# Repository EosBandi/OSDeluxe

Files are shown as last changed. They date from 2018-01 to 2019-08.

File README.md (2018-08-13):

# OSDeluxe

OSDeluxe is a color OSD with four video input, Picture in Picture function for Mavlink flight controllers. It using a Renesas TW2837 Video Mux ASIC
and a Teensy 3.2.

# History

This project, just like many others has a long history. It started as “blue screen” eliminator, for FPV flights. Before custom made FPV monitors, it was a constant problem that normal monitors went dark or blue when video signal become noisy. A cheap video quad switch based on a TW2823 (earlier version of the chip currently used) was reprogrammed to digitize incoming video in a free running mode, and since it already had four inputs and PIP capabilities it was also added to the mix. (The idea come from a Russian webpage http://we.easyelectronics.ru/howwork/kvadrator-izobrazheniya-dlya-sistem-videonablyudeniya.html and “confidential” datasheet of TW2823 was found on Chinese page.) 
The TW2823 chip has color OSD capabilities and it seemed a good idea to make a PIP OSD for FPV use with it. After experimenting for a while it turned out that the speed of OSD functions are too slow to use  for FPV, so the project was stalled. Then a new version of the chip come out, the TW2837 with accelerated OSD functions. Using these functions with some tuned code, now it is possible to have a decent color OSD with around 10Hz refresh rate.

# TW2837
The TW2837 is a four channel video and audio controller designed for security applications by Renesas (Originally TechWell, then Intersil…). It has four PAL/NTSC video decoders (digitizers) and dual video encoders. Video encoders has scalers and video enhancer built in. Decoders and encoders are connected to a MUX engine which provides two display paths and an accelerated graphic overlay (OSD) for each paths. Unlike older TW28xx chips, datasheet for TW2837 is freely available.  (unfortunately OSD sections of the datasheet are quite rudimentary, so it needed a lot’s of experimenting to make it work.)
Communication with the chip can be done via I2C interface (up to 10Mhz!! clock speed) or via a parallel interface.

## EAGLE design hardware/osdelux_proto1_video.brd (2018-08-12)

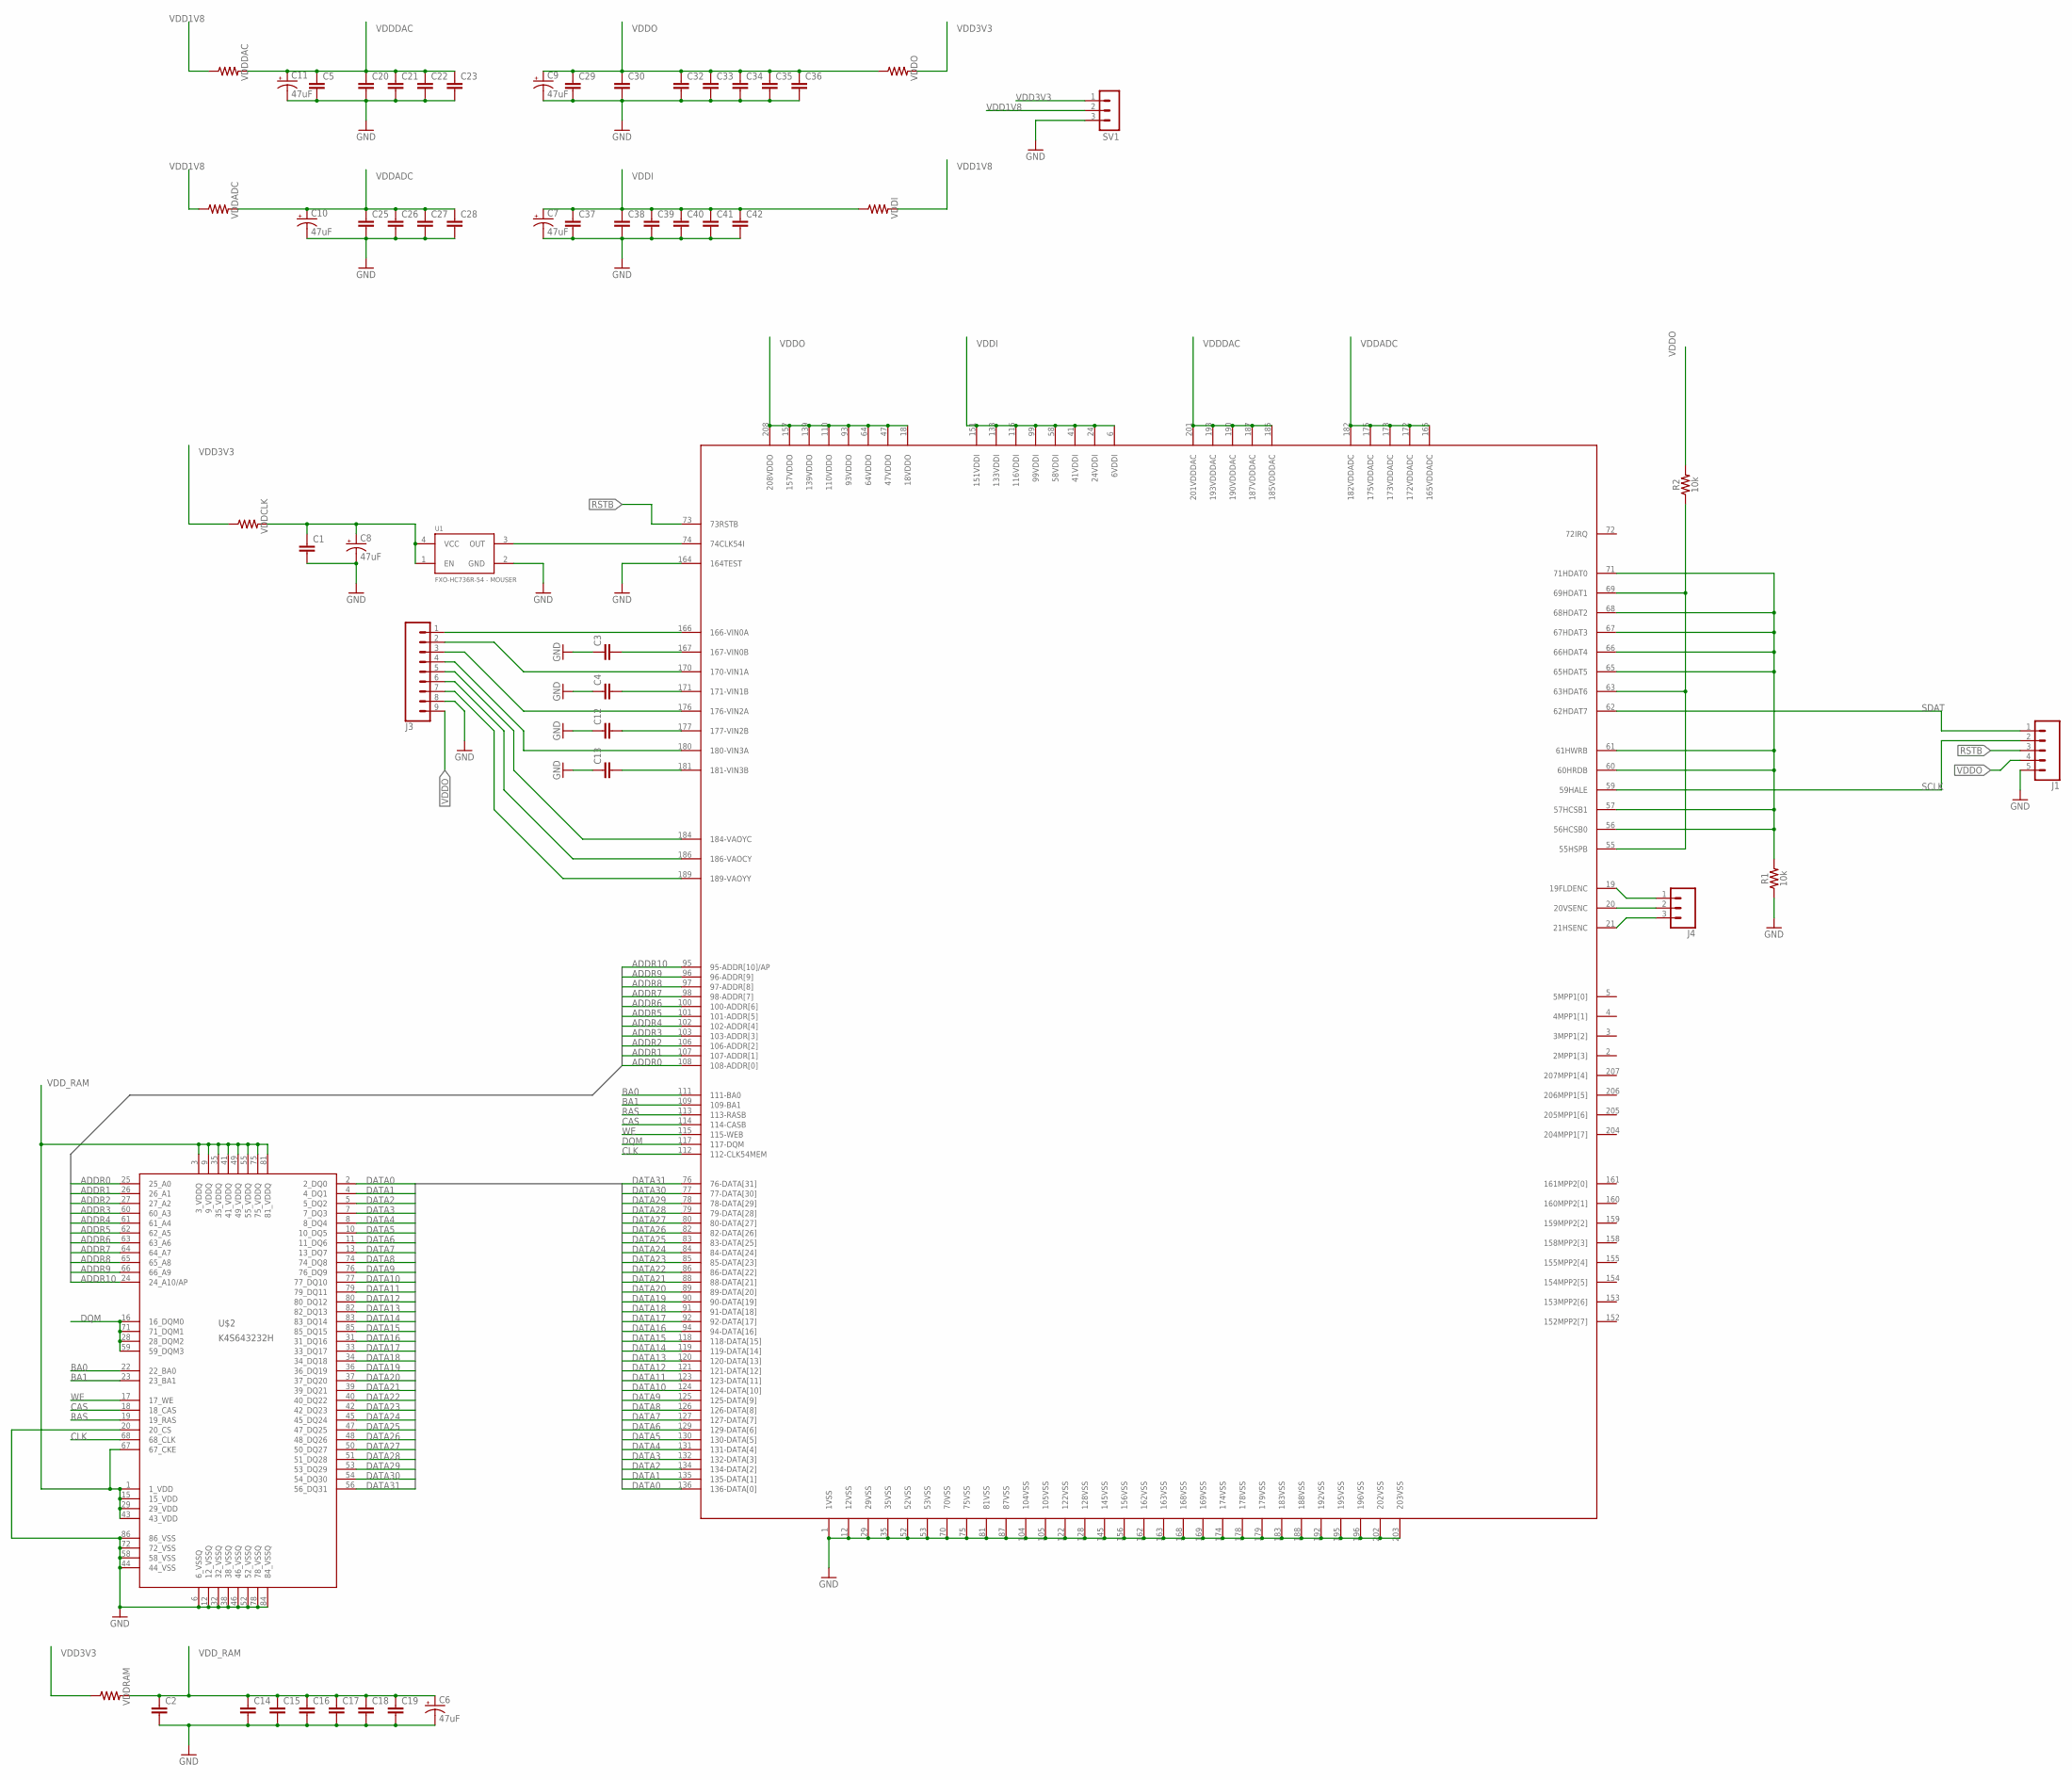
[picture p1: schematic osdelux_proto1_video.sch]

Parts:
C1, C2, C3, C4, C5, C12, C13, C14, C15, C16, C17, C18, C19, C20, C21, C22, C23, C25, C26, C27, C28, C29, C30, C32, C33, C34, C35, C36, C37, C38, C39, C40, C41, C42: CAP0805; 0805
C6, C7, C8, C9, C10, C11: 47uF; EIA3528
J1: CONN_05LOCK_LONGPADS; 1X05_LOCK_LONGPADS
J3: CONN_09LOCK-LONGPADS; 1X09_LOCK_LONGPADS
J4: CONN_03LOCK_LONGPADS; 1X03_LOCK_LONGPADS
R1, R2: 10k; 0805
SV1: MA03-1
U1: FXO-HC736R-54 - MOUSER; CRYSTAL-SMD-7.5X5.2-6PIN
U$1: TW2823; LQFP208
U$2: K4S643232H; TSOP86
VDDADC: 1206
VDDCLK: 1206
VDDDAC: 1206
VDDI: 1206
VDDO: 1206
VDDRAM: 1206

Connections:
72IRQ: U$1.72 (72IRQ)
ADDR0: U$1.108 (108-ADDR[0]), U$2.25 (25_A0)
ADDR1: U$1.107 (107-ADDR[1]), U$2.26 (26_A1)
ADDR2: U$1.106 (106-ADDR[2]), U$2.27 (27_A2)
ADDR3: U$1.103 (103-ADDR[3]), U$2.60 (60_A3)
ADDR4: U$1.102 (102-ADDR[4]), U$2.61 (61_A4)
ADDR5: U$1.101 (101-ADDR[5]), U$2.62 (62_A5)
ADDR6: U$1.100 (100-ADDR[6]), U$2.63 (63_A6)
ADDR7: U$1.98 (98-ADDR[7]), U$2.64 (64_A7)
ADDR8: U$1.97 (97-ADDR[8]), U$2.65 (65_A8)
ADDR9: U$1.96 (96-ADDR[9]), U$2.66 (66_A9)
ADDR10: U$1.95 (95-ADDR[10]/AP), U$2.24 (24_A10/AP)
BA0: U$1.111 (111-BA0), U$2.22 (22_BA0)
BA1: U$1.109 (109-BA1), U$2.23 (23_BA1)
CAS: U$1.114 (114-CASB), U$2.18 (18_CAS)
CLK: U$1.112 (112-CLK54MEM), U$2.68 (68_CLK)
DATA0: U$1.136 (136-DATA[0]), U$2.2 (2_DQ0)
DATA1: U$1.135 (135-DATA[1]), U$2.4 (4_DQ1)
DATA2: U$1.134 (134-DATA[2]), U$2.5 (5_DQ2)
DATA3: U$1.132 (132-DATA[3]), U$2.7 (7_DQ3)
DATA4: U$1.131 (131-DATA[4]), U$2.8 (8_DQ4)
DATA5: U$1.130 (130-DATA[5]), U$2.10 (10_DQ5)
DATA6: U$1.129 (129-DATA[6]), U$2.11 (11_DQ6)
DATA7: U$1.127 (127-DATA[7]), U$2.13 (13_DQ7)
DATA8: U$1.126 (126-DATA[8]), U$2.74 (74_DQ8)
DATA9: U$1.125 (125-DATA[9]), U$2.76 (76_DQ9)
DATA10: U$1.124 (124-DATA[10]), U$2.77 (77_DQ10)
DATA11: U$1.123 (123-DATA[11]), U$2.79 (79_DQ11)
DATA12: U$1.121 (121-DATA[12]), U$2.80 (80_DQ12)
DATA13: U$1.120 (120-DATA[13]), U$2.82 (82_DQ13)
DATA14: U$1.119 (119-DATA[14]), U$2.83 (83_DQ14)
DATA15: U$1.118 (118-DATA[15]), U$2.85 (85_DQ15)
DATA16: U$1.94 (94-DATA[16]), U$2.31 (31_DQ16)
DATA17: U$1.92 (92-DATA[17]), U$2.33 (33_DQ17)
DATA18: U$1.91 (91-DATA[18]), U$2.34 (34_DQ18)
DATA19: U$1.90 (90-DATA[19]), U$2.36 (36_DQ19)
DATA20: U$1.89 (89-DATA[20]), U$2.37 (37_DQ20)
DATA21: U$1.88 (88-DATA[21]), U$2.39 (39_DQ21)
DATA22: U$1.86 (86-DATA[22]), U$2.40 (40_DQ22)
DATA23: U$1.85 (85-DATA[23]), U$2.42 (42_DQ23)
DATA24: U$1.84 (84-DATA[24]), U$2.45 (45_DQ24)
DATA25: U$1.83 (83-DATA[25]), U$2.47 (47_DQ25)
DATA26: U$1.82 (82-DATA[26]), U$2.48 (48_DQ26)
DATA27: U$1.80 (80-DATA[27]), U$2.50 (50_DQ27)
DATA28: U$1.79 (79-DATA[28]), U$2.51 (51_DQ28)
DATA29: U$1.78 (78-DATA[29]), U$2.53 (53_DQ29)
DATA30: U$1.77 (77-DATA[30]), U$2.54 (54_DQ30)
DATA31: U$1.76 (76-DATA[31]), U$2.56 (56_DQ31)
DQM: U$1.117 (117-DQM), U$2.16 (16_DQM0), U$2.28 (28_DQM2), U$2.59 (59_DQM3), U$2.71 (71_DQM1)
FLD: J4.1, U$1.19 (19FLDENC)
GND: C1.2, C2.2, C3.1, C4.1, C5.2, C6.C (-), C7.C (-), C8.C (-), C9.C (-), C10.C (-), C11.C (-), C12.1, C13.1, C14.2, C15.2, C16.2, C17.2, C18.2, C19.2, C20.2, C21.2, C22.2, C23.2, C25.2, C26.2, C27.2, C28.2, C29.2, C30.2, C32.2, C33.2, C34.2, C35.2, C36.2, C37.2, C38.2, C39.2, C40.2, C41.2, C42.2, J1.5, J3.8, R1.1, SV1.3, U1.2 (GND), U$1.1 (1VSS), U$1.12 (12VSS), U$1.29 (29VSS), U$1.35 (35VSS), U$1.52 (52VSS), U$1.53 (53VSS), U$1.70 (70VSS), U$1.75 (75VSS), U$1.81 (81VSS), U$1.87 (87VSS), U$1.104 (104VSS), U$1.105 (105VSS), U$1.122 (122VSS), U$1.128 (128VSS), U$1.145 (145VSS), U$1.156 (156VSS), U$1.162 (162VSS), U$1.163 (163VSS), U$1.164 (164TEST), U$1.168 (168VSS), U$1.169 (169VSS), U$1.174 (174VSS), U$1.178 (178VSS), U$1.179 (179VSS), U$1.183 (183VSS), U$1.188 (188VSS), U$1.192 (192VSS), U$1.195 (195VSS), U$1.196 (196VSS), U$1.202 (202VSS), U$1.203 (203VSS), U$2.6 (6_VSSQ), U$2.12 (12_VSSQ), U$2.20 (20_CS), U$2.32 (32_VSSQ), U$2.38 (38_VSSQ), U$2.44 (44_VSS), U$2.46 (46_VSSQ), U$2.52 (52_VSSQ), U$2.58 (58_VSS), U$2.72 (72_VSS), U$2.78 (78_VSSQ), U$2.84 (84_VSSQ), U$2.86 (86_VSS)
HSYNC: J4.3, U$1.21 (21HSENC)
unnamed: C1.1, C8.A (+), U1.1 (EN), U1.4 (VCC), VDDCLK.2
unnamed: U1.3 (OUT), U$1.74 (74CLK54I)
unnamed: C3.2, U$1.167 (167-VIN0B)
unnamed: C4.2, U$1.171 (171-VIN1B)
unnamed: C12.2, U$1.177 (177-VIN2B)
unnamed: C13.2, U$1.181 (181-VIN3B)
unnamed: R1.2, U$1.56 (56HCSB0), U$1.57 (57HCSB1), U$1.60 (60HRDB), U$1.61 (61HWRB), U$1.65 (65HDAT5), U$1.66 (66HDAT4), U$1.67 (67HDAT3), U$1.68 (68HDAT2), U$1.71 (71HDAT0)
unnamed: R2.1, U$1.55 (55HSPB), U$1.63 (63HDAT6), U$1.69 (69HDAT1)
RAS: U$1.113 (113-RASB), U$2.19 (19_RAS)
RSTB: J1.3, U$1.73 (73RSTB)
SCLK: J1.2, U$1.59 (59HALE)
SDAT: J1.1, U$1.62 (62HDAT7)
VAOCY: J3.6, U$1.186 (186-VAOCY)
VAOYC: J3.5, U$1.184 (184-VAOYC)
VAOYY: J3.7, U$1.189 (189-VAOYY)
VDD1V8: SV1.2, VDDADC.1, VDDDAC.1, VDDI.2
VDD3V3: SV1.1, VDDCLK.1, VDDO.2, VDDRAM.1
VDDADC: C10.A (+), C25.1, C26.1, C27.1, C28.1, U$1.165 (165VDDADC), U$1.172 (172VDDADC), U$1.173 (173VDDADC), U$1.175 (175VDDADC), U$1.182 (182VDDADC), VDDADC.2
VDDDAC: C5.1, C11.A (+), C20.1, C21.1, C22.1, C23.1, U$1.185 (185VDDDAC), U$1.187 (187VDDDAC), U$1.190 (190VDDDAC), U$1.193 (193VDDDAC), U$1.201 (201VDDDAC), VDDDAC.2
VDDI: C7.A (+), C37.1, C38.1, C39.1, C40.1, C41.1, C42.1, U$1.6 (6VDDI), U$1.24 (24VDDI), U$1.41 (41VDDI), U$1.58 (58VDDI), U$1.99 (99VDDI), U$1.116 (116VDDI), U$1.133 (133VDDI), U$1.151 (151VDDI), VDDI.1
VDDO: C9.A (+), C29.1, C30.1, C32.1, C33.1, C34.1, C35.1, C36.1, J1.4, J3.9, R2.2, U$1.18 (18VDDO), U$1.47 (47VDDO), U$1.64 (64VDDO), U$1.93 (93VDDO), U$1.110 (110VDDO), U$1.139 (139VDDO), U$1.157 (157VDDO), U$1.208 (208VDDO), VDDO.1
VDD_RAM: C2.1, C6.A (+), C14.1, C15.1, C16.1, C17.1, C18.1, C19.1, U$2.1 (1_VDD), U$2.3 (3_VDDQ), U$2.9 (9_VDDQ), U$2.15 (15_VDD), U$2.29 (29_VDD), U$2.35 (35_VDDQ), U$2.41 (41_VDDQ), U$2.43 (43_VDD), U$2.49 (49_VDDQ), U$2.55 (55_VDDQ), U$2.67 (67_CKE), U$2.75 (75_VDDQ), U$2.81 (81_VDDQ), VDDRAM.2
VIN0: J3.1, U$1.166 (166-VIN0A)
VIN1: J3.2, U$1.170 (170-VIN1A)
VIN2: J3.3, U$1.176 (176-VIN2A)
VIN3: J3.4, U$1.180 (180-VIN3A)
VSYNC: J4.2, U$1.20 (20VSENC)
WE: U$1.115 (115-WEB), U$2.17 (17_WE)

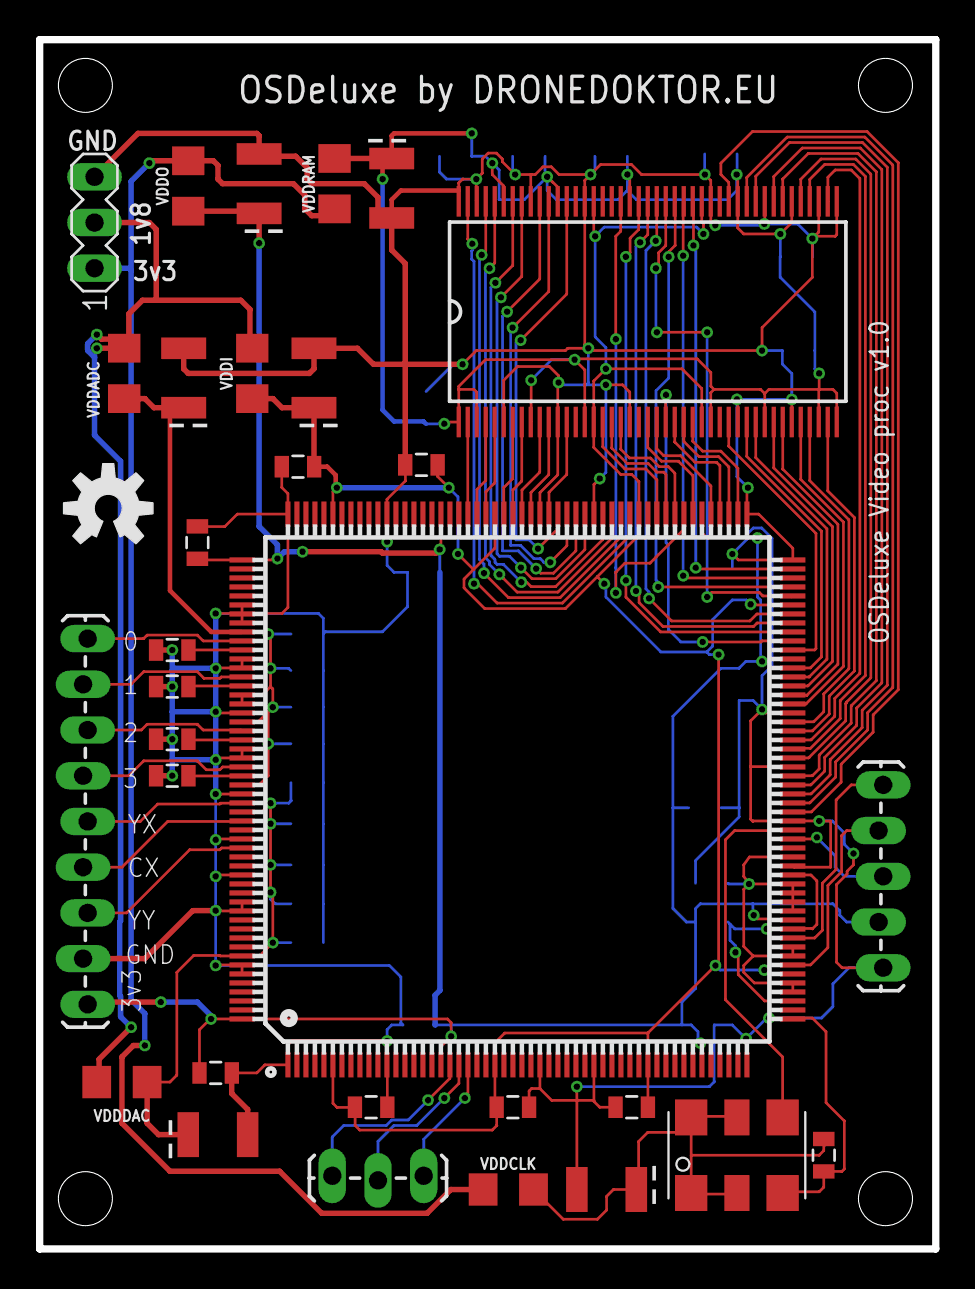
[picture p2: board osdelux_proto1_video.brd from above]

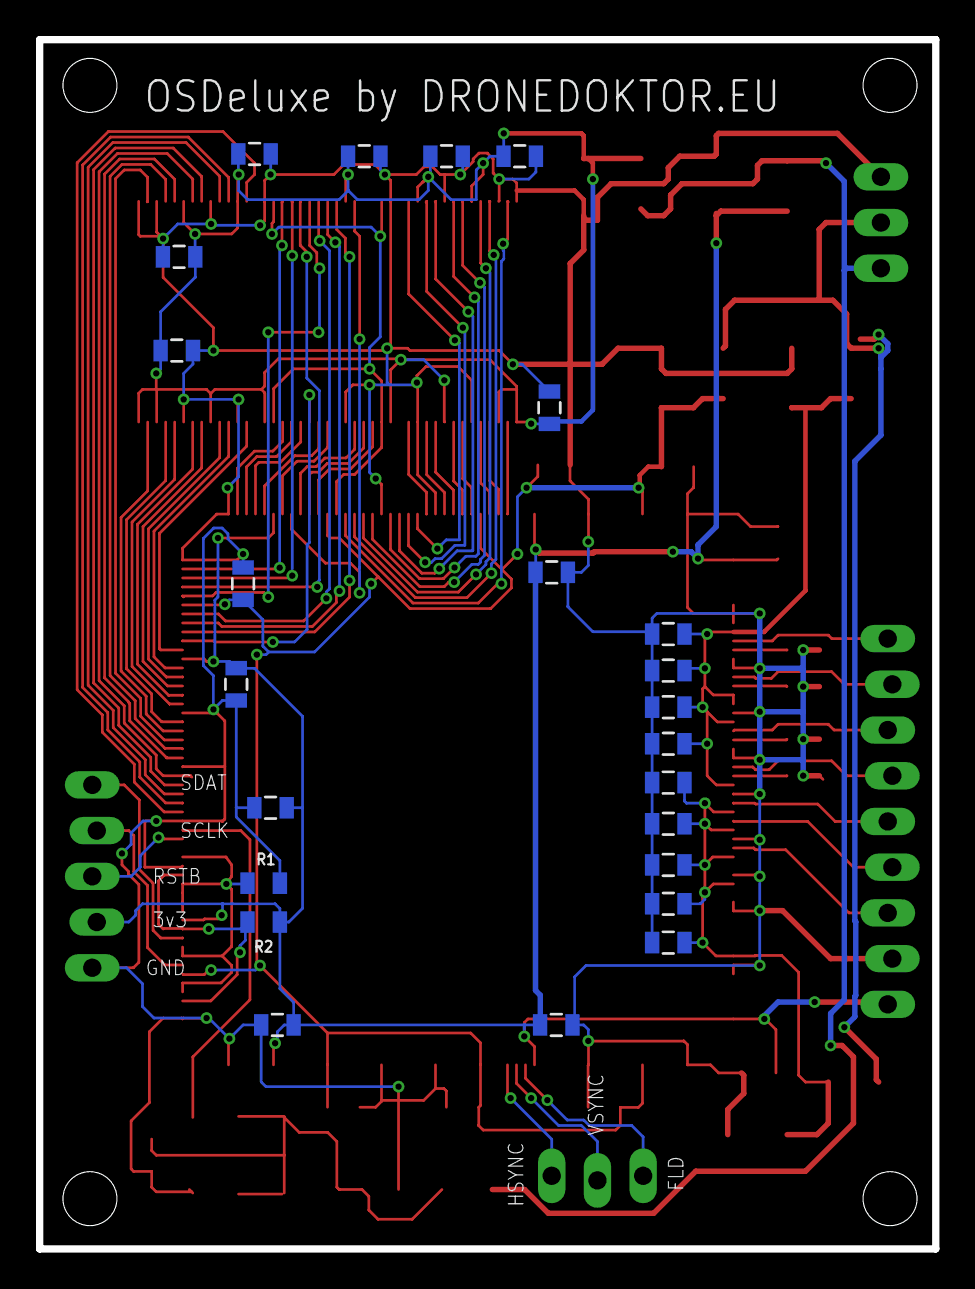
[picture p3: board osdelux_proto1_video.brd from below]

Board: 2 copper layers, 49.8 x 67.2 mm, 56 parts (24 on the bottom side), 79 nets.

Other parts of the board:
U$3: OSHW-LOGO-M

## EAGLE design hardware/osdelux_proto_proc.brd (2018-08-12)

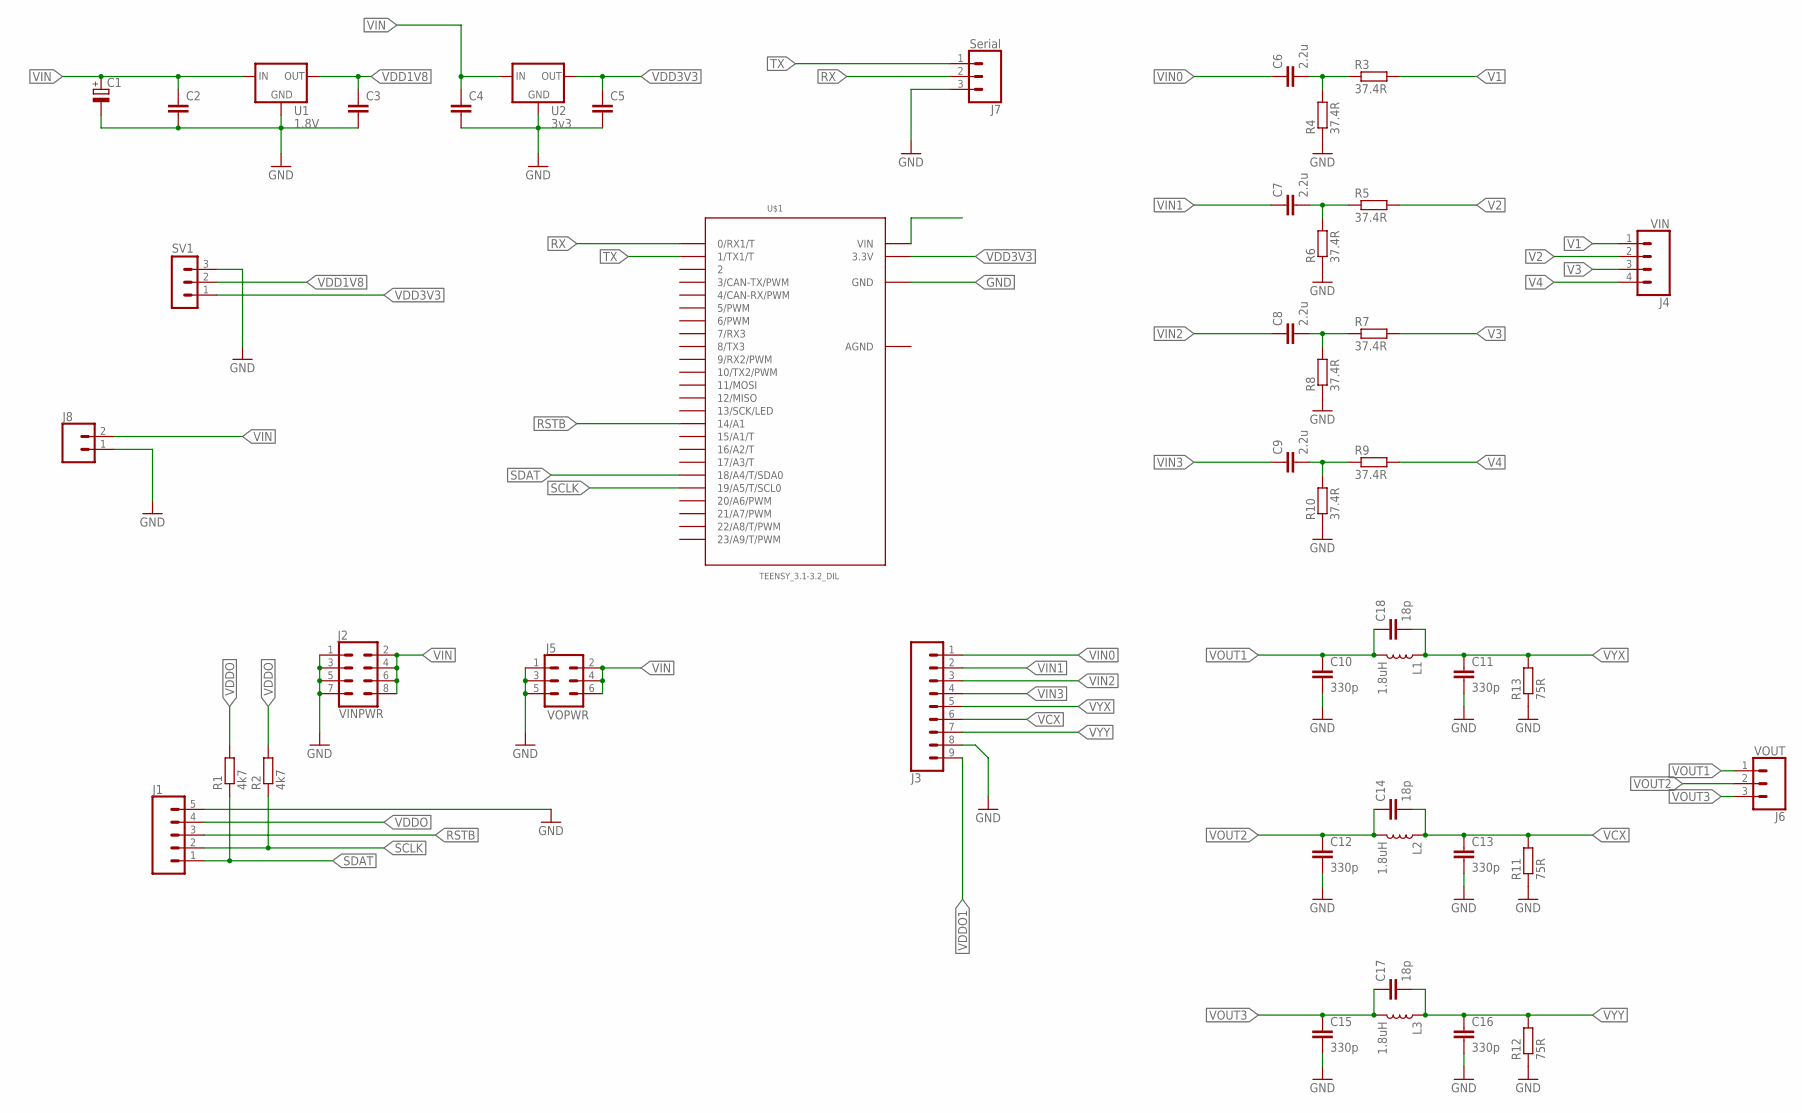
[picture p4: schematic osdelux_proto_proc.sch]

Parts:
C1: CPOL-EUE3.5-8; E3,5-8
C2, C3, C4, C5: C-EUC1206K; C1206K
C6, C7, C8, C9: 2.2u; C1206
C10, C11, C12, C13, C15, C16: 330p; C0805
C14, C17, C18: 18p; C0805
J1: CONN_05LOCK_LONGPADS; 1X05_LOCK_LONGPADS
J2: VINPWR; 2X4
J3: CONN_09LOCK-LONGPADS; 1X09_LOCK_LONGPADS
J4: VIN; 1X04
J5: VOPWR; 2X3
J6: VOUT; 1X03
J7: Serial; 1X03
J8: CONN_02LOCK_LONGPADS; 1X02_LOCK_LONGPADS
L1, L2, L3: 1.8uH; 0805
R1, R2: 4k7; R0805
R3, R4, R5, R6, R7, R8, R9, R10: 37.4R; R0805
R11, R12, R13: 75R; R0805
SV1: MA03-1
U1: 1.8V; DC-DC_CONVERTER_78XX
U2: 3v3; DC-DC_CONVERTER_78XX
U$1: TEENSY_3.1-3.2_DIL; TEENSY_3.0-3.2&LC_DIL

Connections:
AGND: U$1.AGND
DCIN: U$1.VIN
GND: C1.-, C2.2, C3.2, C4.2, C5.2, C10.2, C11.2, C12.2, C13.2, C15.2, C16.2, J1.5, J2.1, J2.3, J2.5, J2.7, J3.8, J5.1, J5.3, J5.5, J7.3, J8.1, R4.1, R6.1, R8.1, R10.1, R11.1, R12.1, R13.1, SV1.3, U1.GND, U2.GND, U$1.GND
unnamed: C6.2, R3.1, R4.2
unnamed: C7.2, R5.1, R6.2
unnamed: C8.2, R7.1, R8.2
unnamed: C9.2, R9.1, R10.2
RSTB: J1.3, U$1.14/A0 (14/A1)
RX: J7.2, U$1.0 (0/RX1/T)
SCLK: J1.2, R2.1, U$1.19/A5 (19/A5/T/SCL0)
SDAT: J1.1, R1.1, U$1.18/A4 (18/A4/T/SDA0)
TX: J7.1, U$1.1 (1/TX1/T)
V1: J4.1, R3.2
V2: J4.2, R5.2
V3: J4.3, R7.2
V4: J4.4, R9.2
VCX: C13.1, C14.2, J3.6, L2.1, R11.2
VDD1V8: C3.1, SV1.2, U1.VOUT (OUT)
VDD3V3: C5.1, SV1.1, U2.VOUT (OUT), U$1.3.3V
VDDO: J1.4, R1.2, R2.2
VDDO1: J3.9
VIN: C1.+, C2.1, C4.1, J2.2, J2.4, J2.6, J2.8, J5.2, J5.4, J5.6, J8.2, U1.VIN (IN), U2.VIN (IN)
VIN0: C6.1, J3.1
VIN1: C7.1, J3.2
VIN2: C8.1, J3.3
VIN3: C9.1, J3.4
VOUT1: C10.1, C18.1, J6.1, L1.2
VOUT2: C12.1, C14.1, J6.2, L2.2
VOUT3: C15.1, C17.1, J6.3, L3.2
VYX: C11.1, C18.2, J3.5, L1.1, R13.2
VYY: C16.1, C17.2, J3.7, L3.1, R12.2

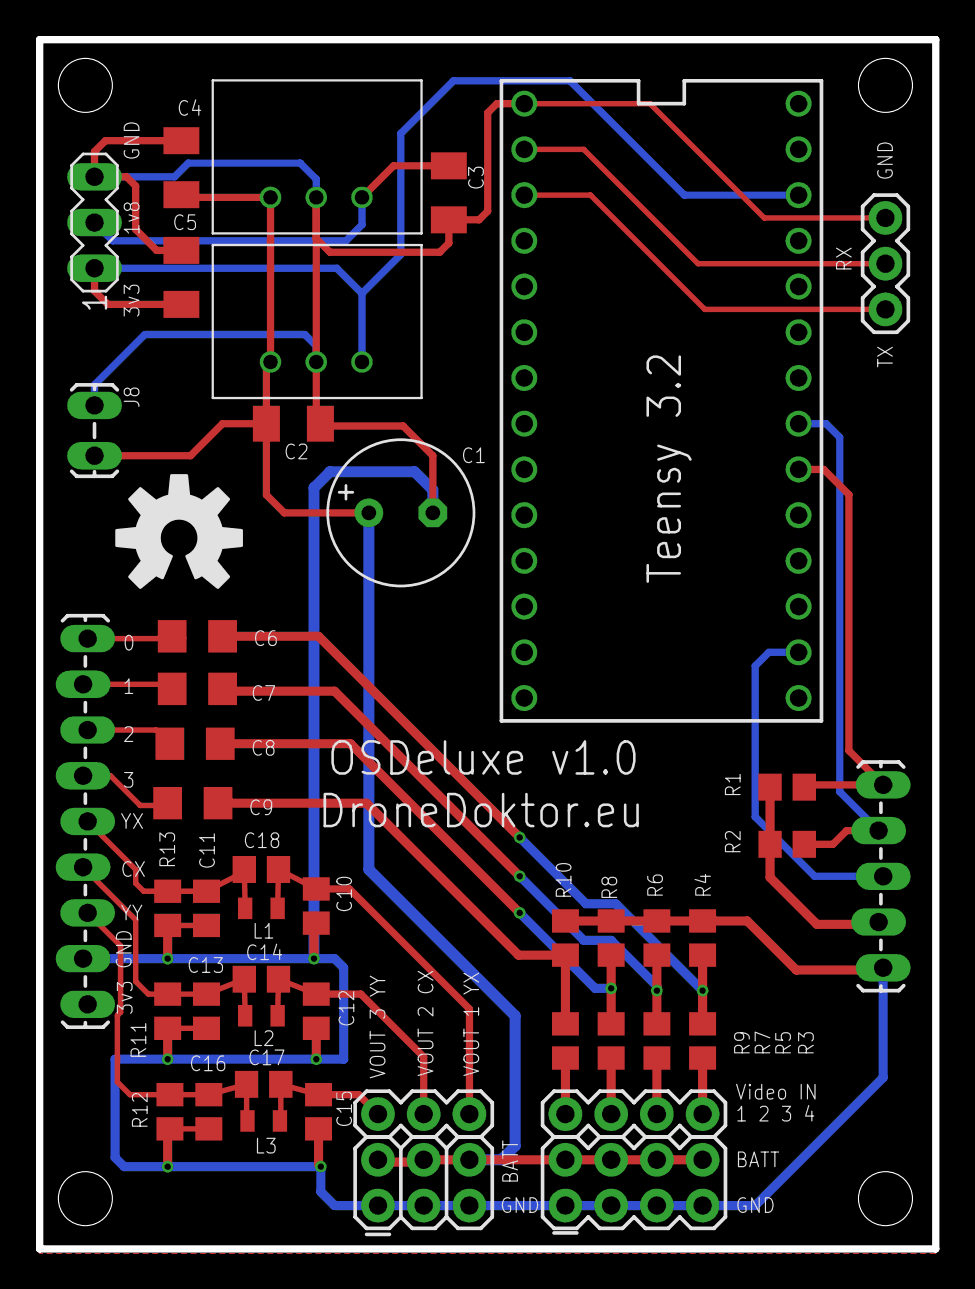
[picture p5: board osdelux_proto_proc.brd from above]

Board: 2 copper layers, 49.8 x 67.2 mm, 47 parts (0 on the bottom side), 28 nets.

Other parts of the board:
U$2: OSHW-LOGO-L

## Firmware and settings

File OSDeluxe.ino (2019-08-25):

/*
    OSDeluxe - Color PIP Mavlink OSD
    Copyright (C) 2018  Andras Schaffer - Dronedoktor.eu

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
    With Grateful Acknowledgements to the projects:
        AlceOSD by Luis Alves
        PlayUAV OSD
        Brain FPV Flight Controller(https://github.com/BrainFPV/TauLabs) by Tau Labs

 */

//#define TW2837_I2C
#include "cli.h"
#define TW2837_MPP

#include "OSDeluxe.h"

#ifdef TW2837_I2C

#define TW_RESET 14

#else

#define TW_RESET 23

#define TW_CS 22
#define TW_WR 12
#define TW_RD 11
#define TW_AEN 15

#endif

#define LED_PIN 13

global_variables_t g;

void setup()
{
    pinMode(LED_PIN, OUTPUT);
    pinMode(TW_RESET, OUTPUT);

#ifndef TW2837_I2C

    pinMode(TW_CS, OUTPUT);
    pinMode(TW_WR, OUTPUT);
    pinMode(TW_RD, OUTPUT);
    pinMode(TW_AEN, OUTPUT);

    digitalWriteFast(TW_CS, 1);
    digitalWriteFast(TW_WR, 1);
    digitalWriteFast(TW_RD, 1);
    digitalWriteFast(TW_AEN, 0);

    setWriteDirInline();
#endif

    // Reset TW2837
    delay(1000);
    digitalWrite(TW_RESET, LOW);
    delay(500);
    digitalWrite(TW_RESET, HIGH);
    delay(500);

    // Setup for Master mode, pins 18/19, internal pullups, 4Mhz, 10ms default timeout
    // It is not a mistake TW2837 works fine on 4Mhz I2C speed

#ifndef TW2837_I2C
    Wire.begin(I2C_MASTER, 0x00, I2C_PINS_18_19, I2C_PULLUP_INT, 4000000, I2C_OP_MODE_IMM);
    Wire.setDefaultTimeout(1000); // 10ms
#endif

    // Open USB serial port for debug and UI
    Serial.begin(115200);

    // Open Serial1 port for MavLink communication
    // TODO: make it configurable
    Serial1.begin(115200);
}

void loop()
{
    // Led ON
    digitalWrite(LED_PIN, HIGH);

    // Initn TW2837 registers
    tw_init();

    g.pip_page = 0;

    tw_write_register(0x0c8, 0x03);
    tw_write_register(0x057, 0x00); // Extra coring for sharepning

    tw_write_register(0x240, 0x01);

    // We will use these screens
    // Don't clear all since pages above 0 share memory with scratch table (Not mentioned in the datasheet)

    OSD256_clear_screen(PTH_X, 0); // Main Path page 0
    OSD256_clear_screen(PTH_X, 1); // Main Path page 1

    OSD256_clear_screen(PTH_Y, 0); // Secondary Path page 0 - draw static elements on this page

    OSD256_set_display_page(0); // Display page 0

    load_settings();
    if ((osd.eeprom_version != EEPROM_VERSION) || (osd.settings_size != sizeof(osd)))
    {
        default_settings();
        save_settings();
    }

    update_vout_settings(); // Apply vout settings from saved values
    update_vin_settings();  // Apply vin settings from saved values
    update_pip();           // Set up PIP state

    g.displayed_mode = -1; // Signal startup

    g.mode = 0;

    // Clear buffers for mavlink messages
    memset(&g.message_buffer, 0, sizeof(g.message_buffer));
    memset(&g.message_archive, 0, sizeof(g.message_archive));

    g.message_buffer_line = 0;
    g.message_buffer_display_time = 0;

    // Start with osd_page 1 and pip page 0
    g.visible_osd_page = 0x01; // bit coded
    g.pip_page = 0x00;

    init_home();

    get_parameter_count();
    param_send_index = total_params;

    // Display both fields !!!!
    tw_write_register(0x20f, 0x0f);

    // OSD write will use page0
    OSD256_wr_page = 0;

    g.arming_status = false;
    g.displayed_arming_status = true;
    g.armed_start_time = 0;
    g.last_capacity_query = 0;
    g.debug_looptime = 0;
    memset(&g.vario_graph, 0, sizeof(g.vario_graph));
    g.vgraph_idx = 0;
    osd_draw_boundary = { 0, 0, SCR_X_SIZE, SCR_Y_SIZE };
    g.pthy_redraw = true;
    g.launch_heading = NO_HEADING;
    g.detected_cell_count = 0; // 0 means not detected yet

    // Commented out for quick start, need to run at every powerup

    OSD256_init_font_tables();
    OSD256_init_bitmaps();

    OSD256_clear_screen(PTH_X, 0);
    OSD256_clear_screen(PTH_X, 1);

    // From now on we assume that extended OSD functions are enabled...
    tw_write_register(0x240, 0x01);

    unsigned long now;

    // As start we display page 0 and write to page 1 (to enusure flicker free display refresh)
    // OSD256_wr_page and set_display_page only influence PTH_X display path
    OSD256_wr_page = 1;
    OSD256_set_display_page(0);

    init_cli();

    // Main loop
    while (1)
    {
        now = millis();

        read_mavlink();
        read_cli();

        // Clear actual write page (not the one that is displayed)
        OSD256_clear_screen(PTH_X, OSD256_wr_page);

        // OSD256_displayscratch();

        // g.visible_osd_page = 0x01;
        // g.pip_page = 0x01;

        // Render OSD elements
        osd_boxes_render();

        if (osd.radar1.visible & g.visible_osd_page) osd_render_radar(&osd.radar1);
        if (osd.radar2.visible & g.visible_osd_page) osd_render_radar(&osd.radar2);
        if (osd.radar3.visible & g.visible_osd_page) osd_render_radar(&osd.radar3);
        if (osd.vgraph.visible & g.visible_osd_page) osd_render_vgraph(&osd.vgraph);
        if (osd.compass.visible & g.visible_osd_page) osd_render_compass(&osd.compass);
        if (osd.center_cross_visible & g.visible_osd_page) osd_render_center_marker();
        if (osd.move.visible & g.visible_osd_page) osd_render_move(&osd.move);
        if (osd.horizon.visible & g.visible_osd_page) osd_render_horizona(&osd.horizon);
        if (osd.gps.visible & g.visible_osd_page) osd_render_gps(&osd.gps);
        if (osd.stat.visible & g.visible_osd_page) osd_render_status(&osd.stat);
        if (osd.batt1_v.visible & g.visible_osd_page) osd_render_batt_volt(&osd.batt1_v, g.b1_voltage);
        if (osd.batt2_v.visible & g.visible_osd_page) osd_render_batt_volt(&osd.batt2_v, g.b2_voltage);
        if (osd.batt1_cap.visible & g.visible_osd_page) osd_render_batt_cap(&osd.batt1_cap, g.b1_remaining_capacity);
        if (osd.batt1_curr.visible & g.visible_osd_page) osd_render_batt_curr(&osd.batt1_curr, g.b1_current);
        if (osd.batt2_curr.visible & g.visible_osd_page) osd_render_batt_curr(&osd.batt2_curr, g.b2_current);
        if (osd.batt1_power.visible & g.visible_osd_page) osd_render_batt_power(&osd.batt1_power, g.b1_power);
        if (osd.batt2_power.visible & g.visible_osd_page) osd_render_batt_power(&osd.batt2_power, g.b2_power);
        if (osd.alt.visible & g.visible_osd_page) osd_render_altitude(&osd.alt);
        if (osd.vario.visible & g.visible_osd_page) osd_render_vario(&osd.vario);
        if (osd.home_w.visible & g.visible_osd_page) osd_render_home(&osd.home_w);
        if (osd.mode.visible & g.visible_osd_page) osd_render_flmode(&osd.mode);
        if (osd.pull.visible & g.visible_osd_page) osd_render_pull_force(&osd.pull);
        if (osd.msg_widget.visible & g.visible_osd_page) osd_render_message_buffer();
        if (osd.gs.visible & g.visible_osd_page) osd_render_groundspeed(&osd.gs);
        if (osd.thr.visible & g.visible_osd_page) osd_render_throttle(&osd.thr);
        if (osd.msg_list_widget.visible & g.visible_osd_page) osd_render_message_list();
        if (osd.rssi.visible & g.visible_osd_page) osd_render_rssi(&osd.rssi);
        if (osd.pt_widget.visible & g.visible_osd_page) osd_render_pt_indicator(&osd.pt_widget);
        if (osd.ekf_detail.visible & g.visible_osd_page) osd_render_ekf_detail(&osd.ekf_detail);
        if (osd.vibe_detail.visible & g.visible_osd_page) osd_render_vibe_detail(&osd.vibe_detail);
		if (osd.rc_out.visible & g.visible_osd_page) osd_render_rcout(&osd.rc_out);

        // Renders done, switch working page for smooth redraw
        OSD256_set_display_page(OSD256_wr_page);
        if (OSD256_wr_page == 0)
            OSD256_wr_page = 1;
        else
            OSD256_wr_page = 0;

        // The full redraw cycle has ended, we assume all PTHY redraws were done as well
        g.pthy_redraw = false;

        // Control channel 1 - Control PIP mode
        if (g.ctr_saved_state[0] != g.ctr_state[0])
        {
            // There is a change in ctr1 state
            g.ctr_saved_state[0] = g.ctr_state[0]; // Save it, to prevent unneccessary state changes in the main loop
            g.pip_page = g.ctr_state[0];

            for (uint8_t i = 1; i < 5; i++)
            {
                tw_ch_set_input(i, osd.video_channels[g.pip_page][i].input);

                tw_ch_settings(i, osd.video_channels[g.pip_page][i].enable, osd.video_channels[g.pip_page][i].popup);

                tw_ch_set_window(i, osd.video_channels[g.pip_page][i].pos_h, osd.video_channels[g.pip_page][i].pos_v, osd.video_channels[g.pip_page][i].len_h);
            }
        }

        // Control channel 2 - OSD widgets page

        if (g.ctr_saved_state[1] != g.ctr_state[1])
        {
            // There is a change in ctr1 state
            g.ctr_saved_state[1] = g.ctr_state[1]; // Save it, to prevent unneccessary state changes in the main loop
            // visible_osd_page is a bit coded value bit represents the one page (1 - page 1, 2-page 2, 4-page 3, 8-page 4.... up to page 5)
            g.visible_osd_page = 0x01 << g.ctr_state[1];
            g.pthy_redraw = true;          // force redraw of pth_y elements as well.
            OSD256_clear_screen(PTH_Y, 0); // And clean the pthy display
        }

        // check heartbeat
        heartbeat_validation();

        // Send eight params at once, to speed up parameter download time
        if (param_send_index != total_params)
        {
            for (int i = 0; i < 8; i++) send_param_list();
        }

        // Send out mavlink heartbeat
        if ((millis() - last_heartbeat_sent) >= 1000)
        {
            heartbeat_out();
            last_heartbeat_sent = millis();
        }

        if (millis() > (g.home.last_calc + HOME_CALC_INTERVAL)) calc_home();
        find_launch_heading();
        if ((osd.batt1_cap.max_capacity == 0) && (millis() > (g.last_capacity_query + 5000))) request_mavlink_battery_capacity();

        g.debug_looptime = false;
        if (g.debug_looptime) debug("Looptime : %lu\r\n", millis() - now);
    }
}

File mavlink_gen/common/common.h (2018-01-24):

/** @file
 *  @brief MAVLink comm protocol generated from common.xml
 *  @see http://mavlink.org
 */
#pragma once
#ifndef MAVLINK_COMMON_H
#define MAVLINK_COMMON_H

#ifndef MAVLINK_H
    #error Wrong include order: MAVLINK_COMMON.H MUST NOT BE DIRECTLY USED. Include mavlink.h from the same directory instead or set ALL AND EVERY defines from MAVLINK.H manually accordingly, including the #define MAVLINK_H call.
#endif

#undef MAVLINK_THIS_XML_IDX
#define MAVLINK_THIS_XML_IDX 1

#ifdef __cplusplus
extern "C" {
#endif

// MESSAGE LENGTHS AND CRCS

#ifndef MAVLINK_MESSAGE_LENGTHS
#define MAVLINK_MESSAGE_LENGTHS {}
#endif

#ifndef MAVLINK_MESSAGE_CRCS
#define MAVLINK_MESSAGE_CRCS {{0, 50, 9, 0, 0, 0}, {1, 124, 31, 0, 0, 0}, {2, 137, 12, 0, 0, 0}, {4, 237, 14, 3, 12, 13}, {5, 217, 28, 1, 0, 0}, {6, 104, 3, 0, 0, 0}, {7, 119, 32, 0, 0, 0}, {11, 89, 6, 1, 4, 0}, {20, 214, 20, 3, 2, 3}, {21, 159, 2, 3, 0, 1}, {22, 220, 25, 0, 0, 0}, {23, 168, 23, 3, 4, 5}, {24, 24, 30, 0, 0, 0}, {25, 23, 101, 0, 0, 0}, {26, 170, 22, 0, 0, 0}, {27, 144, 26, 0, 0, 0}, {28, 67, 16, 0, 0, 0}, {29, 115, 14, 0, 0, 0}, {30, 39, 28, 0, 0, 0}, {31, 246, 32, 0, 0, 0}, {32, 185, 28, 0, 0, 0}, {33, 104, 28, 0, 0, 0}, {34, 237, 22, 0, 0, 0}, {35, 244, 22, 0, 0, 0}, {36, 222, 21, 0, 0, 0}, {37, 212, 6, 3, 4, 5}, {38, 9, 6, 3, 4, 5}, {39, 254, 37, 3, 32, 33}, {40, 230, 4, 3, 2, 3}, {41, 28, 4, 3, 2, 3}, {42, 28, 2, 0, 0, 0}, {43, 132, 2, 3, 0, 1}, {44, 221, 4, 3, 2, 3}, {45, 232, 2, 3, 0, 1}, {46, 11, 2, 0, 0, 0}, {47, 153, 3, 3, 0, 1}, {48, 41, 13, 1, 12, 0}, {49, 39, 12, 0, 0, 0}, {50, 78, 37, 3, 18, 19}, {51, 196, 4, 3, 2, 3}, {54, 15, 27, 3, 24, 25}, {55, 3, 25, 0, 0, 0}, {61, 167, 72, 0, 0, 0}, {62, 183, 26, 0, 0, 0}, {63, 119, 181, 0, 0, 0}, {64, 191, 225, 0, 0, 0}, {65, 118, 42, 0, 0, 0}, {66, 148, 6, 3, 2, 3}, {67, 21, 4, 0, 0, 0}, {69, 243, 11, 0, 0, 0}, {70, 124, 18, 3, 16, 17}, {73, 38, 37, 3, 32, 33}, {74, 20, 20, 0, 0, 0}, {75, 158, 35, 3, 30, 31}, {76, 152, 33, 3, 30, 31}, {77, 143, 3, 3, 8, 9}, {81, 106, 22, 0, 0, 0}, {82, 49, 39, 3, 36, 37}, {83, 22, 37, 0, 0, 0}, {84, 143, 53, 3, 50, 51}, {85, 140, 51, 0, 0, 0}, {86, 5, 53, 3, 50, 51}, {87, 150, 51, 0, 0, 0}, {89, 231, 28, 0, 0, 0}, {90, 183, 56, 0, 0, 0}, {91, 63, 42, 0, 0, 0}, {92, 54, 33, 0, 0, 0}, {93, 47, 81, 0, 0, 0}, {100, 175, 26, 0, 0, 0}, {101, 102, 32, 0, 0, 0}, {102, 158, 32, 0, 0, 0}, {103, 208, 20, 0, 0, 0}, {104, 56, 32, 0, 0, 0}, {105, 93, 62, 0, 0, 0}, {106, 138, 44, 0, 0, 0}, {107, 108, 64, 0, 0, 0}, {108, 32, 84, 0, 0, 0}, {109, 185, 9, 0, 0, 0}, {110, 84, 254, 3, 1, 2}, {111, 34, 16, 0, 0, 0}, {112, 174, 12, 0, 0, 0}, {113, 124, 36, 0, 0, 0}, {114, 237, 44, 0, 0, 0}, {115, 4, 64, 0, 0, 0}, {116, 76, 22, 0, 0, 0}, {117, 128, 6, 3, 4, 5}, {118, 56, 14, 0, 0, 0}, {119, 116, 12, 3, 10, 11}, {120, 134, 97, 0, 0, 0}, {121, 237, 2, 3, 0, 1}, {122, 203, 2, 3, 0, 1}, {123, 250, 113, 3, 0, 1}, {124, 87, 35, 0, 0, 0}, {125, 203, 6, 0, 0, 0}, {126, 220, 79, 0, 0, 0}, {127, 25, 35, 0, 0, 0}, {128, 226, 35, 0, 0, 0}, {129, 46, 22, 0, 0, 0}, {130, 29, 13, 0, 0, 0}, {131, 223, 255, 0, 0, 0}, {132, 85, 14, 0, 0, 0}, {133, 6, 18, 0, 0, 0}, {134, 229, 43, 0, 0, 0}, {135, 203, 8, 0, 0, 0}, {136, 1, 22, 0, 0, 0}, {137, 195, 14, 0, 0, 0}, {138, 109, 36, 0, 0, 0}, {139, 168, 43, 3, 41, 42}, {140, 181, 41, 0, 0, 0}, {141, 47, 32, 0, 0, 0}, {142, 72, 243, 0, 0, 0}, {143, 131, 14, 0, 0, 0}, {144, 127, 93, 0, 0, 0}, {146, 103, 100, 0, 0, 0}, {147, 154, 36, 0, 0, 0}, {148, 178, 60, 0, 0, 0}, {149, 200, 30, 0, 0, 0}, {230, 163, 42, 0, 0, 0}, {231, 105, 40, 0, 0, 0}, {232, 151, 63, 0, 0, 0}, {233, 35, 182, 0, 0, 0}, {234, 150, 40, 0, 0, 0}, {241, 90, 32, 0, 0, 0}, {242, 104, 52, 0, 0, 0}, {243, 85, 53, 1, 52, 0}, {244, 95, 6, 0, 0, 0}, {245, 130, 2, 0, 0, 0}, {246, 184, 38, 0, 0, 0}, {247, 81, 19, 0, 0, 0}, {248, 8, 254, 3, 3, 4}, {249, 204, 36, 0, 0, 0}, {250, 49, 30, 0, 0, 0}, {251, 170, 18, 0, 0, 0}, {252, 44, 18, 0, 0, 0}, {253, 83, 51, 0, 0, 0}, {254, 46, 9, 0, 0, 0}, {256, 71, 42, 3, 8, 9}, {257, 131, 9, 0, 0, 0}, {258, 187, 32, 3, 0, 1}, {259, 92, 235, 0, 0, 0}, {260, 146, 5, 0, 0, 0}, {261, 179, 27, 0, 0, 0}, {262, 12, 18, 0, 0, 0}, {263, 133, 255, 0, 0, 0}, {264, 49, 28, 0, 0, 0}, {265, 26, 16, 0, 0, 0}, {266, 193, 255, 3, 2, 3}, {267, 35, 255, 3, 2, 3}, {268, 14, 4, 3, 2, 3}, {269, 58, 246, 0, 0, 0}, {270, 232, 247, 3, 14, 15}, {299, 19, 96, 0, 0, 0}, {300, 217, 22, 0, 0, 0}, {310, 28, 17, 0, 0, 0}, {311, 95, 116, 0, 0, 0}, {320, 243, 20, 3, 2, 3}, {321, 88, 2, 3, 0, 1}, {322, 243, 149, 0, 0, 0}, {323, 78, 147, 3, 0, 1}, {324, 132, 146, 0, 0, 0}, {330, 23, 158, 0, 0, 0}}
#endif

#include "../protocol.h"

#define MAVLINK_ENABLED_COMMON

// ENUM DEFINITIONS


/** @brief Micro air vehicle / autopilot classes. This identifies the individual model. */
#ifndef HAVE_ENUM_MAV_AUTOPILOT
#define HAVE_ENUM_MAV_AUTOPILOT
typedef enum MAV_AUTOPILOT
{
   MAV_AUTOPILOT_GENERIC=0, /* Generic autopilot, full support for everything | */
   MAV_AUTOPILOT_RESERVED=1, /* Reserved for future use. | */
   MAV_AUTOPILOT_SLUGS=2, /* SLUGS autopilot, http://slugsuav.soe.ucsc.edu | */
   MAV_AUTOPILOT_ARDUPILOTMEGA=3, /* ArduPilotMega / ArduCopter, http://diydrones.com | */
   MAV_AUTOPILOT_OPENPILOT=4, /* OpenPilot, http://openpilot.org | */
   MAV_AUTOPILOT_GENERIC_WAYPOINTS_ONLY=5, /* Generic autopilot only supporting simple waypoints | */
   MAV_AUTOPILOT_GENERIC_WAYPOINTS_AND_SIMPLE_NAVIGATION_ONLY=6, /* Generic autopilot supporting waypoints and other simple navigation commands | */
   MAV_AUTOPILOT_GENERIC_MISSION_FULL=7, /* Generic autopilot supporting the full mission command set | */
   MAV_AUTOPILOT_INVALID=8, /* No valid autopilot, e.g. a GCS or other MAVLink component | */
   MAV_AUTOPILOT_PPZ=9, /* PPZ UAV - http://nongnu.org/paparazzi | */
   MAV_AUTOPILOT_UDB=10, /* UAV Dev Board | */
   MAV_AUTOPILOT_FP=11, /* FlexiPilot | */
   MAV_AUTOPILOT_PX4=12, /* PX4 Autopilot - http://pixhawk.ethz.ch/px4/ | */
   MAV_AUTOPILOT_SMACCMPILOT=13, /* SMACCMPilot - http://smaccmpilot.org | */
   MAV_AUTOPILOT_AUTOQUAD=14, /* AutoQuad -- http://autoquad.org | */
   MAV_AUTOPILOT_ARMAZILA=15, /* Armazila -- http://armazila.com | */
   MAV_AUTOPILOT_AEROB=16, /* Aerob -- http://aerob.ru | */
   MAV_AUTOPILOT_ASLUAV=17, /* ASLUAV autopilot -- http://www.asl.ethz.ch | */
   MAV_AUTOPILOT_SMARTAP=18, /* SmartAP Autopilot - http://sky-drones.com | */
   MAV_AUTOPILOT_ENUM_END=19, /*  | */
} MAV_AUTOPILOT;
#endif
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

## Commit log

2018-02-03 ekf, current, armed
2018-02-03 battery capacity request from controller
2018-03-03 Batt capacity query reinstate
2018-04-01 Added message_achive but it is too slow for constant rendering, must be moved to rec or need scratch buffer font display....
    [OSDeluxe.ino, settings.h]
2018-04-08 bitmap handling, bar drawing and battery, alt widgets rewrite for OSD256 done
    [16x20char_designer.xlsx]
2018-04-08 converting to osd256 commencted out old osd functions
    [16x20char_designer.xlsx]
2018-04-08 Center marker added Ground speed added
    [16x20char_designer.xlsx]
2018-04-10 Bar behind data line at he bottom. Quick fix for GigaCopter6. Will move to a optional settings later.
    [OSDeluxe.ino]
2018-04-16 Code cleanup Compass widget Vario graph widget Speedup OSD256_block_fill
    [16x20char_designer.xlsx]
2018-04-17 Battery cell autodetect Radar first implementation
2018-08-12 Add rssi moved string to strings.h Do some code cleanup for clean compile
    [16x20char_designer.xlsx]
2018-08-12 Added hw design files
    [osdelux_proto1_video.brd, osdelux_proto1_video.sch, osdelux_proto_proc.brd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]

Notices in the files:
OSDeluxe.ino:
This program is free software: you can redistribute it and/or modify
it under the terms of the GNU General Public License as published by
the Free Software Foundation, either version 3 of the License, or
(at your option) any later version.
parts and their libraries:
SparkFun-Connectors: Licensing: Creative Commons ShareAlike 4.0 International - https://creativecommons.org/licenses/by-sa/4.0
